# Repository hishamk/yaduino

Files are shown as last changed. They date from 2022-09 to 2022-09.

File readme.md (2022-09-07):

## The Yaduino - An ATmega328P playground
So this is my first stab at designing a microcontroller board. I call it Yaduino - Yet Another Arduino (the missing r is deliberate!) :)

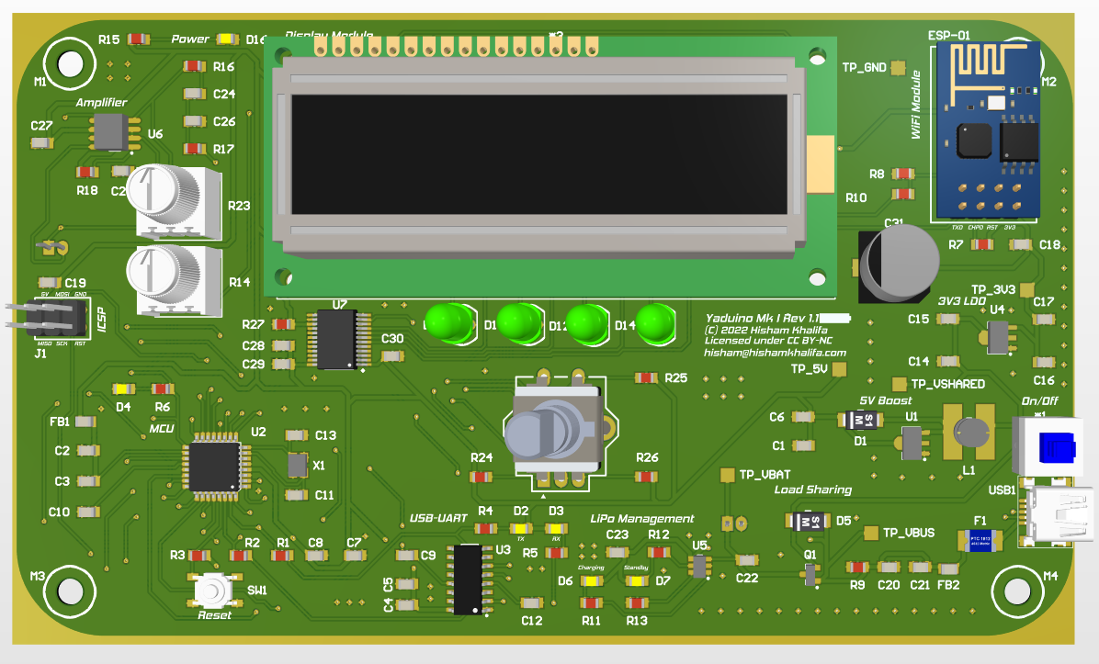
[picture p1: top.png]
Top PCB image


Since I used CircuitMaker for schematic and PCB design, this project is also hosted on [CircuitMaker's project hub](https://circuitmaker.com/Projects/Details/HishamKhalifa-2/ATmega328-Playground).

A [YouTube video](https://youtu.be/OaU7GNxLcCE) of the Yaduino.

### Design Goals
This project does not necessarily "make sense" since a million other boards could do more, with less components and a smaller footprint. My aim with this project was to learn microcontroller board design and to figure out how to implement my (somewhat arbitrary) design goals for the 8-bit ATmega328 microcontroller.

The choice of MCU and components was mainly driven by the fact that I also had most materials (or closely related counterparts) to breadboard most of the design before committing it to PCB manufacture. Besides, what's the fun in using other boards when you can learn to make your own and have fun while at it?

 1. Should function as a regular Arduino (complete with ICSP for burning
    the bootloader).

 2. Should use as many SMD parts as possible from JLC's parts library so
    that I can utilize their assembly service to some extent.
    
 3.  Should include easily accessible headers for plugging in either an
    I2C VFD/OLED display or a serial 1602A display.
    
 4. Should work with a LiPo as well as USB power and have a proper
    battery management circuit, boost circuit and load sharing circuit.
    
 5. Should have a provision for plugging in an ESP-8266 ESP-01 module to add WiFi
    access (a little bit of 32-bit goodness at play here).
    
 6. Should have at least one optional IC, such as a demux, with some
    blinkenlights for good measure. This may be disabled using a solder
    jumper.
    
 7.  Should have some input facility, such as a rotary encoder/button.
    
 8.  Should look good without a case as well as with a case.
    
 9. Silkscreen should be informative and cool, because why not.

### Fixed Issues 

This board has been fully built, tested and debugged. All mistakes listed below have been fixed as of this version (but not built, as the bodge wire version with the fixes works fine).

The issues were:

 1. ESP stability. ESP-8266 ESP-01 requires more than 200mA at startup. This needs clean power. Fixed with 100uF bypass.

 2. Board was receiving serial data (RX) but was unable to transmit (TX). Culprit was too small resistor value on TX LED. It was 1K. Changed to 3K3 and that fixed it. It seems the LED was drawing too much current away from the actual 
TX signal destined to the CH340C USB-UART IC.

3. Forgot to connect supply on the charge management IC! Bodge wire to the rescue!

4. Messed up volume POT connections. Had full resistance of POT (10K or 20K depending on POT used), instead of actual setting. Fixed with bodge wire and POT pin gymnastics and PCB trace cut.

 5. 1602A lines-to-pins silkscreen on bottom side was incorrect in a couple of places.
 
### Assembly

I ordered the PCBs from JLC and utilized their assembly service. The main components that I had to solder myself where: the ATmega328P-AU (drag solder and some solder wick does the trick), headers, POTS and the various bodge/fixes.

### Programming
  
So once the board is full assembled, you'll want to burn the Arduino bootloader onto it. Assuming you have a factory-fresh ATmega 328 with no set fuses, this process should not pose any issues.

*Tip*
You can use [AVRFuses](https://vonnieda.org/software/avrfuses) to check the fuse settings on the ATmega328 using a USBasp connected to the ICSP header.

To burn the bootloader and start uploading Arduino sketches:

1. Connect a USBasp to the ICSP header on the Yaduino and the other end of the cable to your computer.

2. Install the [MiniCore](https://github.com/MCUdude/MiniCore) package on your computer (and before that, the Arduino IDE if not already installed).

3. In the Arduino IDE, select MiniCore | Atmega328 for the Board, then select External 16MHz for clock, 2.7v for BOD, EEPROM retained for EEPROM, LTO Disabed for LTO Compiler, 328P/328PA for the Variant, YES (UART10) for the Bootloader.

4. Set the programmer to "USBasp (MiniCore)".

5. Select Burn Bootloader.

6. Once the bootloader is burned successfully, select AVRISP mkII (MiniCore) for the programmer.

7. You may disconnect the USBasp at this point and connect via the micro USB connection. Your board is now ready to receive and run Arduino code.

### ESP-8266 / WiFi

 To use an ESP-8266 ESP-01 with the Yaduino, you'll need to use the [WiFIESPAT](https://github.com/jandrassy/WiFiEspAT) library.

I opted to use [v2.2.0.0](https://github.com/jandrassy/UnoWiFiDevEdSerial1/wiki/files/ESP8266-1MB-tx1rx3-AT_V2.2.zip) of the firmware. You may need to update the firmware using a basic circuit and a USB-UART board (Google it, it's out there). Make sure you have a 100uF bypass cap if you're facing temperamental issues with either 
updating the firmware or testing it. A lot of these schematics on the net do not have this cap specified.

Once your firmware is updated, you'll have to change the baud rate to 9600. You may do this manually using AT commands after updating the fimrware, or you could:

1. Plug the ESP-8266 into the Yaduino.

2. Load the ChangeATBaudRate sketch in the WiFiESPAT library's examples folder.

3. Change the Software Serial ports to 11 and 10 instead of 6 and 7.

4. Upload sketch.

5. Your ESP-8266 should now work at 9600.

The reason Software Serial is used for the ESP-8266 connection is due to the fact that the hardware serial pins are also used for the 1602A display. Yes, I know, if you use an I2C display this wouldn't be an issue - but I wanted to 
design it with this constraint to see if I can get everything working fine.

### Example Code

 The example code does a few things:

1. Displays text on 1602A.

2. Connects to WiFi (make sure you run the WiFiESPAT examples folder sketch "SetUp PersistentWiFiConnection" to set your WiFi details first.)

3. Displays IP address and some other fidgety things on clicking/rotating.

4. Runs a telnet server. Connect to port 2323 from another machine and type in a message. It'll get displayed on the Yaduino!

### Enclosures

I've designed and printed a few [enclosures](https://a360.co/3RtZ853) using Fusion 360 and printed them on a Prusa Mini+ using PLA filaments.

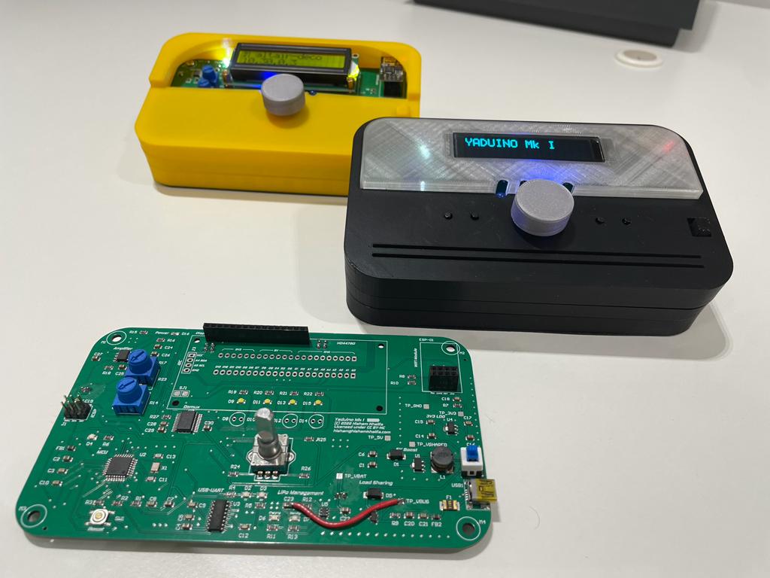
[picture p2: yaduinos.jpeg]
Yaduinos image


## Inspiration

This project is partially inspired by the [Simonduino](https://circuitmaker.com/Projects/Details/Andre-LaMothe/Simonduino-Color-Match-Game) project which in turn is based off the Arduino Nano. The Simonduino is used in Andre LaMothe's course on [Udemy](https://www.udemy.com/course/crash-course-electronics-and-pcb-design/).

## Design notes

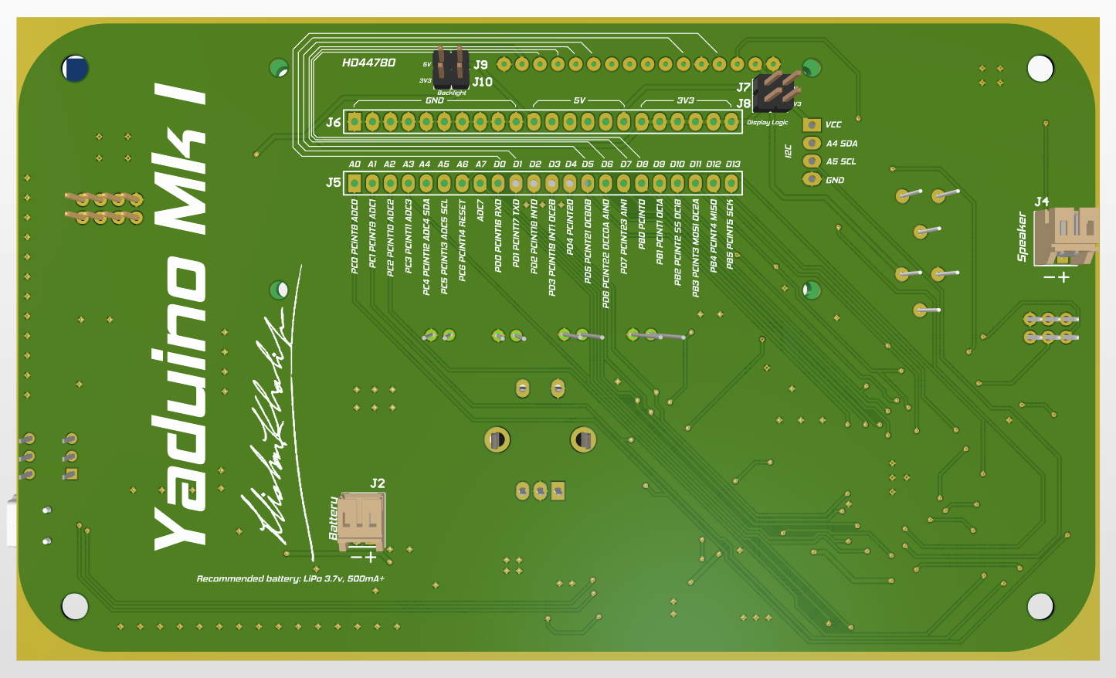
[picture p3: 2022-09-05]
bottom.png

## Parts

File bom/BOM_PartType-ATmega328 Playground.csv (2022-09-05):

Comment | Designator | Footprint | Description | LibRef | Quantity
E-Switch TL2285EE | *1 | E-Switch TL2285EE-Footprint-1 | Switch Push Button ON ON DPDT Plunger 0.1A 30VDC Latching PC Pins Thru-Hole | CMP-c0ee09f4e8cc1f29-8 | 1
Generic rotary encoder | *2 | PCB-o3j4y8d2fld7qcbr9m3z-1 | Generic rotary encoder | CMP-xheecen9eoauhc53c92k-2 | 1
LCD 1602A | *3 | PCB-ex3up7xxohmyvq6bxg3y-1 | LCD Display | CMP-27dcefe9db18f81b-4 | 1
22uF | C1, C6, C7 | PCB-6lexfyg45u8dooebomjp-1 | Generic 805 ceramic cap | CMP-2j4q9hwmgv2koyvfzfsm-2 | 3
10uF | C2, C4, C14, C16, C20, C22, C23, C27, C29, C30 | PCB-6lexfyg45u8dooebomjp-1 | Generic 805 ceramic cap | CMP-2j4q9hwmgv2koyvfzfsm-2 | 10
0.1uF (100nF) | C3, C5, C8, C9, C10, C12, C15, C17, C18, C19, C21, C28 | PCB-6lexfyg45u8dooebomjp-1 | Generic 805 ceramic cap | CMP-2j4q9hwmgv2koyvfzfsm-2 | 12
15pF | C11, C13 | PCB-6lexfyg45u8dooebomjp-1 | Generic 805 ceramic cap | CMP-2j4q9hwmgv2koyvfzfsm-2 | 2
0.39uF (390nF) | C24 | PCB-6lexfyg45u8dooebomjp-1 | Generic 805 ceramic cap | CMP-2j4q9hwmgv2koyvfzfsm-2 | 1
1uF | C25, C26 | PCB-6lexfyg45u8dooebomjp-1 | Generic 805 ceramic cap | CMP-2j4q9hwmgv2koyvfzfsm-2 | 2
100uF | C31 | EEHZC1H101P | Generic 805 electrolytic capacitor | CMP-vk94xb3d6va75m91xos3-1 | 1
SS14 DO214 | D1, D5 | DO-214 | SS14 DO214 | CMP-1ixnt5ul191www8k67rw-2 | 2
Generic 805 LED | D2, D3, D4 | PCB-6lexfyg45u8dooebomjp-1 | Generic 805 LED | CMP-3miidwgmeqlikwr8bjjy-1 | 3
Charge Status LED | D6 | PCB-6lexfyg45u8dooebomjp-1 | Generic 805 LED | CMP-3miidwgmeqlikwr8bjjy-1 | 1
Standby Status LED | D7 | PCB-6lexfyg45u8dooebomjp-1 | Generic 805 LED | CMP-3miidwgmeqlikwr8bjjy-1 | 1
Output LED | D8, D10, D12, D14 | PCB-b5vk7vz0xhkw7l0fnova-1 | LED Uni-Color Green 2-Pin T-1 3/4 Bulk | CMP-92bb5b2eff764d7c-3 | 4
2 | D9 | PCB-6lexfyg45u8dooebomjp-1 | Generic 805 LED | CMP-3miidwgmeqlikwr8bjjy-1 | 1
 | D11, D13, D15 | PCB-6lexfyg45u8dooebomjp-1 | Generic 805 LED | CMP-3miidwgmeqlikwr8bjjy-1 | 3
Status LED 2 | D16 | PCB-6lexfyg45u8dooebomjp-1 | Generic 805 LED | CMP-3miidwgmeqlikwr8bjjy-1 | 1
Jameco Valuepro ESP8266 ESP-01S | ESP-01 | Jameco Valuepro ESP8266 ESP-01S-Footprint-1 | ESP-01S ESP8266 WiFi Module | CMP-8c81432480f65346-5 | 1
Resettable protection fuse | F1 | PCB-jtgmhik4xw0hzz22xc7c-1 | PTC Resettable Fuse 0.5A(hold) 1A(trip) 15V 100A 0.8W 0.15s 0.15Ohm SMD Solder Pad 1812 T/R | CMP-277735-10 | 1
1.5K@100MHz | FB1, FB2 | PCB-d2agyush773fxqrs9gs3-1 | PBY201209T 1500R 1000mA 0, 30R RoHSconf | CMP-31b8f9c7a15aee7f-1 | 2
 | J1 | PCB-2h1t0rpz2tx2wsc79kkt-1 | 2.54mm (0.1") Pitch DIL Vertical PC Tail Pin Header, 6.1mm mating pin height, tin, 3+3 contacts | M20-9980346 | 1
JST S2B-PH-K-S (LF)(SN) | J2 | PCB-bjczsn0p3ptzfqad6r12-1 | Conn Shrouded Header (4 Sides) HDR 2 POS 2mm Solder RA Thru-Hole Box | CMP-ffbd36e62648207a-2 | 1
Generic 1.25mm 4 pin female header | J3 | PCB-aav6o8fn6okscn0g86ph-1 | Generic 1.25mm 4 pin female header | CMP-0es61uybg75kwez52rvg-1 | 1
Speaker | J4 | PCB-bjczsn0p3ptzfqad6r12-1 | Conn Shrouded Header (4 Sides) HDR 2 POS 2mm Solder RA Thru-Hole Box | CMP-ffbd36e62648207a-2 | 1
Generic 2.54mm 22 pin female header | J5, J6 | PCB-aav6o8fn6okscn0g86ph-1 | Generic 2.54mm 22 pin female header | CMP-b4ui2xh0qsgjy2za9ieg-1 | 2
 | J7, J8, J9, J10 | PCB-header | Connector, Through Hole, Header, 2, 2.54 mm 2pin | CMP-74e0bf2ff245ab27-13 | 4
HRO U-F-M5SS-W-2 | J11 | PCB-udy8oed33uo11narwln1-1 | Conn; Data; USB; Mini-B; SMT; Rt Angle; Solder Tabs; On-The-Go; PCB Pegs; LF | CMP-d87211734df407b5-14 | 1
22uH | L1 | PCB-jclg0i9eyiwxcv2vi73d-1 | Inductor Power Wirewound 22uH 20% 1KHz 20Q-Factor Ferrite 1.5A 110mOhm DCR T/R | CMP-a103680bca1b7ec4-1 | 1
Keystone 4816 | M1, M2, M3, M4 | PCB-mb8dqtsky67usueely79-1 | TEKTON 4816 1/2-Inch Drive Shallow Impact Socket Set, SAE, 15-Piece | CMP-d4321d38e40b0bf5-1 | 4
Alpha & Omega Semiconductor AO3401A | Q1 | PCB-kx100zt0qwbp6gbfpfbn-1 | MOSFET P-CH 30V 4A SOT23 | CMP-832298-9 | 1
1K | R1, R2, R5, R6, R10, R11, R12, R17 | PCB-6lexfyg45u8dooebomjp-1 | Generic 805 resistor | CMP-5huzuqma9w3n6iha3gac-1 | 8
10K | R3, R7, R9, R18, R24, R25, R26, R27 | PCB-6lexfyg45u8dooebomjp-1 | Generic 805 resistor | CMP-5huzuqma9w3n6iha3gac-1 | 8
3K3 | R4 | PCB-6lexfyg45u8dooebomjp-1 | Generic 805 resistor | CMP-5huzuqma9w3n6iha3gac-1 | 1
2K2 | R8 | PCB-6lexfyg45u8dooebomjp-1 | Generic 805 resistor | CMP-5huzuqma9w3n6iha3gac-1 | 1
2K | R13 | PCB-6lexfyg45u8dooebomjp-1 | Generic 805 resistor | CMP-5huzuqma9w3n6iha3gac-1 | 1
0-10K | R14 | RES-Bourns-3386 | Res Cermet Trimmer 5K Ohm 10% 1/2W 1(Elec)/1(Mech)Turn 8.38mm (9.53 X 9.53 X 10.41mm) Pin Thru-Hole Tube | CMP-57749e7438e988b3-1 | 1
470R | R15, R19, R20, R21, R22 | PCB-6lexfyg45u8dooebomjp-1 | Generic 805 resistor | CMP-5huzuqma9w3n6iha3gac-1 | 5
20K | R16 | PCB-6lexfyg45u8dooebomjp-1 | Generic 805 resistor | CMP-5huzuqma9w3n6iha3gac-1 | 1
0-100K | R23 | RES-Bourns-3386 | Res Cermet Trimmer 5K Ohm 10% 1/2W 1(Elec)/1(Mech)Turn 8.38mm (9.53 X 9.53 X 10.41mm) Pin Thru-Hole Tube | CMP-57749e7438e988b3-1 | 1
Jumper pads | SJ1 | New footprint 1 | Jumper pads | CMP-4ca9tqewk6jxev977wve-7 | 1
 | SW1 | PCB-3slrmfp54cqpjmkc7eq7-1 | Switch Tactile N.O. SPST Round Button Gull Wing 0.02A 15VDC 1000000Cycles 1.569N SMD T/R | CMP-f30a391dc9bb2ccd-2 | 1
2x2mm-pad | TP_3V3, TP_5V, TP_GND, TP_VBAT, TP_VBUS, TP_VSHARED | PCB-iek5qk9ganu4yn12lo6h-1 | Raychem; SMT Circuit probe pad, 0805, 0R0 RCT | RCT-0C | 6
ME2108A/50 | U1 | SOT-89-MB3_N | DC/DC Step Up Converter | CMP-w3jwqw8rtfk6e8mw7z1w-1 | 1
ATMEGA328P-AU | U2 | TQFP32-08 | Embedded microcontroller ATMEGA328P-AU TQFP 32 (7x7) Microchip Technology 8-Bit 20 MHz I/O number 23 | ATMEGA328P-AU | 1
CH340C UART | U3 | CYP-SX16_L | CH340C UART | CMP-cjy4raao81rihiu0fmjx-3 | 1
Holtek HT7333A | U4 | SOT-89_M | Fixed Low Drop Positive Voltage Regulator, 3.3V, 4-Pin SOT-89, 3-Pin TO-02, Tape and Reel | CMP-f9d135d015f72616-1 | 1
TP4057 Linear Li-Ion Battery Charger 500mA | U5 | DBV6_L | TP4057 Linear Li-Ion Battery Charger 500mA | CMP-pmi864c5akpbqamag5jn-2 | 1
BL62810SO-R | U6 | SOIC-SN8_M | 1.1W x 1 @ 8O 2.2V ~ 5.5V Class AB SOIC-8_150mil Audio Power OpAmps ROHS | CMP-pd4wvmbbrd8m1k4bw0eq-2 | 1
TI CD74HC4067 (SSOP) | U7 | PCB-9xotwbubxedzd6tjqrkr-1 | High Speed CMOS 16-Channel Analog Multiplexer/Demultiplexer 24-SSOP -55 to 125 | CMP-106ed96303d9cfa9-15 | 1
16MHz CL 9pF | X1 | PCB-73bh49k2ct94buydgloj-1 | Crystal 16Mhz 3225 SMD | CMP-c6a10a47defa1966-1 | 1

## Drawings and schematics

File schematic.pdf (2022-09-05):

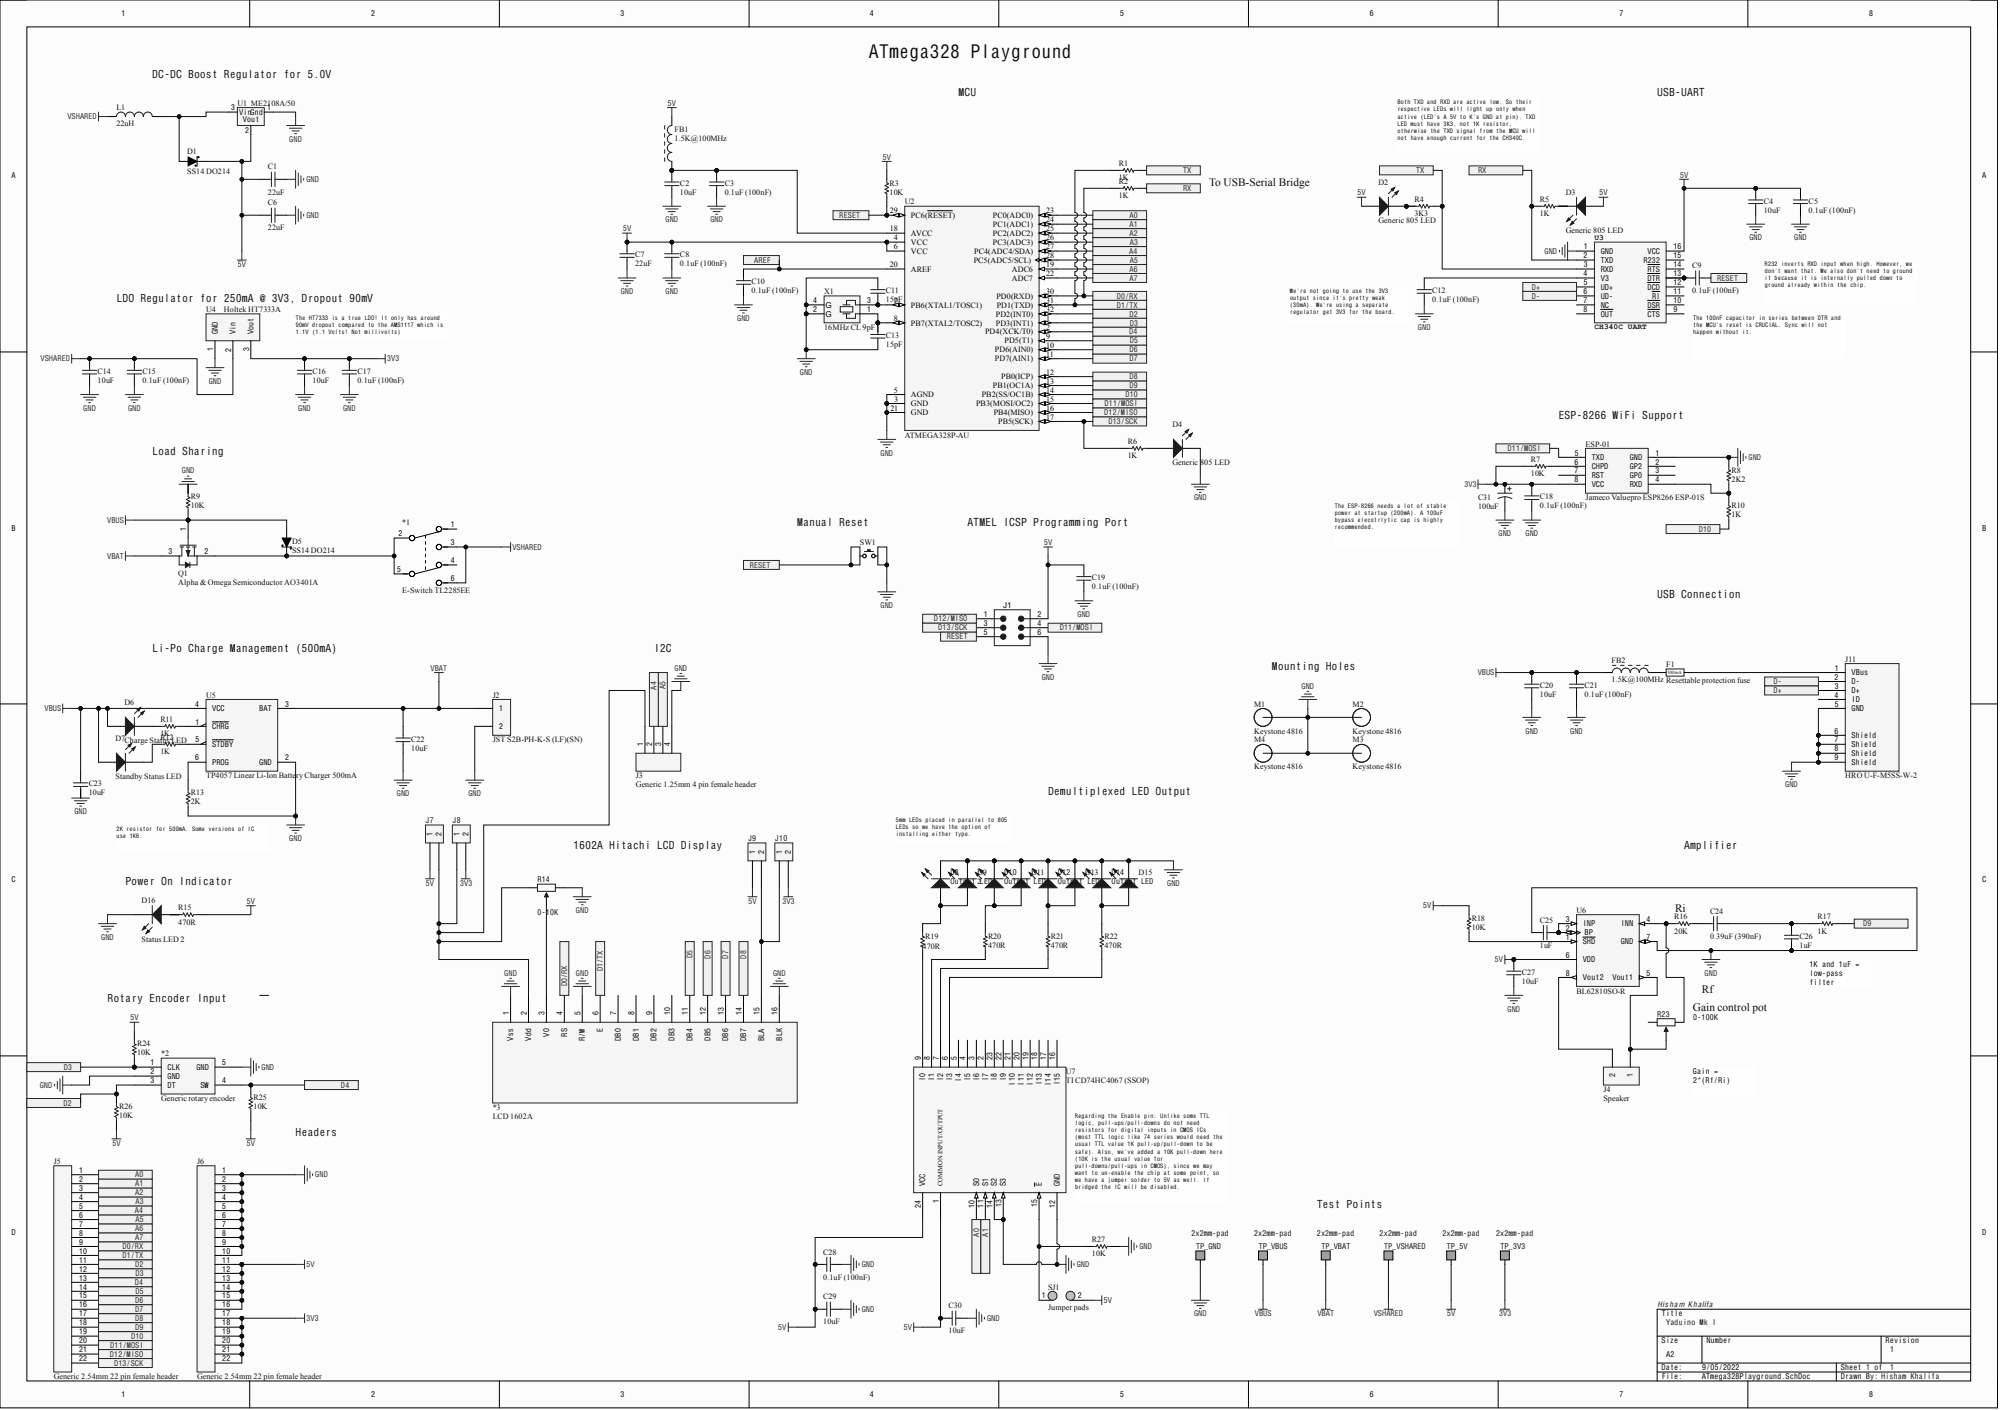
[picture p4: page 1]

DC-DC Boos t Regu l a t o r f o r 5 . 0V

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

LDO Regu l a t o r f o r 250mA @ 3V3 , Dr opou t 90mV

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

GND 1 U4 Holtek HT7333A The HT7333 i s a t r ue LDO! I t on l y has a r ound

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

90mV d r opou t compa r ed t o t he AMS1117 wh i ch i s

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

L i -Po Cha r ge Managemen t ( 500mA)

JST S2B-PH-K-S (LF)(SN)

TP4057 Linear Li-Ion Battery Charger 500mA

Generic 1.25mm 4 pin female header

Demu l t i p l e x ed LED Ou t pu t

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

2K r es i s t o r f o r 500mA . Some ve r s i ons o f I C
use 1K6 .

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

Generic 2.54mm 22 pin female header

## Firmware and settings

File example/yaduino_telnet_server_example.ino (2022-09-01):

#include <SoftwareSerial.h>

#include <LiquidCrystal.h>

#include <EncoderButton.h>

#include <WiFiEspAT.h>

#define BIT(n, i)(n >> i & 1)
#define esp8266Speed 9600

SoftwareSerial esp8266(11, 10); // rx, tx

int lastPosition;

WiFiClient client;

const int MAX_CLIENTS = 3;
const int CLIENT_CONN_TIMEOUT = 3600; // seconds. 1 hour
WiFiServerPrint server(2323);

LiquidCrystal lcd(0, 1, 5, 6, 7, 8); // 0 = rxPin, 1 = txPin Parameters: (rs, enable, d4, d5, d6, d7)
EncoderButton eb1(2, 3, 4); // INT0 and INT1 hardware interrupt pins are 2 and 3. We use them so that we can read the encoder using interrupts rather than polling on every cycle which would be laggy/unreliable!

String s;

byte yaduinoLogo[] = {
  B10100,
  B10100,
  B11100,
  B00110,
  B11101,
  B00101,
  B00101,
  B00110
};

byte wifiLogo[] = {
  B10101,
  B10101,
  B11101,
  B11101,
  B00000,
  B11101,
  B11001,
  B10001
};

byte ok[] = {
  B11110,
  B10010,
  B10010,
  B11110,
  B00101,
  B00110,
  B00110,
  B00101
};

byte no[] = {
  B10010,
  B11010,
  B10110,
  B10010,
  B01111,
  B01001,
  B01001,
  B01111
};

byte smiley[] = {
  B11011,
  B11011,
  B00100,
  B00100,
  B10001,
  B10001,
  B01110,
  B00000
};

void setup() {
  // set up the LCD's number of columns and rows:
 
  lcd.begin(16, 2);
  lcd.createChar(0,yaduinoLogo);
  lcd.createChar(1,wifiLogo);

  //Link the event(s) to your function
  eb1.setClickHandler(onEb1Clicked);
  eb1.setEncoderHandler(onEb1Encoder);

  pinMode(14, OUTPUT);
  pinMode(15, OUTPUT);
  pinMode(16, OUTPUT);

  digitalWrite(14, LOW);
  digitalWrite(15, LOW);
  digitalWrite(16, LOW);

  for (int source = 0; source < 4; source++) {
    delay(300);
    selectSource(source);
  }

  delay(300);
  selectSource(0);

  esp8266.begin(esp8266Speed);
  WiFi.init(esp8266);
  WiFi.hostname("yaduino-yellow");

  printWelcome();
  delay(2000);
  lcdReset();

  if (WiFi.status() == WL_NO_MODULE) {
    lcd.print("WiFi error!");
    // don't continue
    while (true);
  }

  // waiting for connection to Wifi network set with the SetupWiFiConnection sketch
  lcd.write(byte(1));
  lcd.print(" Connecting");
  while (WiFi.status() != WL_CONNECTED) {
    delay(1000);
    lcd.print('.');
  }

  server.begin(MAX_CLIENTS, CLIENT_CONN_TIMEOUT);
  printNetInfo();
}

void lcdReset() {
  lcd.clear();
//  lcd.blink();
  lcd.setCursor(0, 0);
}

void printNetInfo() {
  lcdReset();
  IPAddress ip = WiFi.localIP();
  lcd.write(byte(1));
  lcd.print(" ");
  lcd.print(WiFi.SSID());
  lcd.setCursor(0, 1);
  lcd.print(ip);
}

void printLove() {
  lcdReset();
  lcd.print("I love you.");
  lcd.setCursor(0, 1);
  lcd.print(":)");
}

void printWelcome() {
  lcdReset();
  lcd.print("   Welcome to");
  lcd.setCursor(0, 1);
  lcd.print(" ");
  lcd.write(byte(0));
  lcd.print(" Yaduino Mk I");
}

void loop() {
  eb1.update();

  WiFiClient client = server.available(); // returns first client which has data to read or a 'false' client
  if (client) { // client is true only if it is connected and has data to read
    s = client.readStringUntil('\n'); // read the message incoming from one of the clients
    s.trim(); // trim eventual \r
    updateMessage(s);
    client.print("echo: "); // this is only for the sending client
    server.println(s); // send the message to all connected clients
    server.flush(); // flush the buffers
  }
}

void updateMessage(String msg) {
  lcdReset();
  lcd.print(msg);
  if (s.length() > 16) {
    delay(1000);
  }
}

void onEb1Clicked(EncoderButton & eb) {
  tone(9, 100, 10);
  //  lcd.clear();
  lcd.setCursor(0, 0);
  // Print a message to the LCD.
  lcd.print("Button click   ");
  lcd.setCursor(13, 0);
  lcd.print(eb.clickCount());
  lcd.setCursor(0, 1);
  lcd.print("                ");

  if (eb.clickCount() == 2) {
    printNetInfo();
  } else if (eb.clickCount() == 3) {
    printLove();
  }
}


void levelSet(int d) {
  static int level=-1;
  lcd.setCursor(0,0);
  lcd.print("VOLUME          ");
  level += d;

  lcd.setCursor(0,1);
  for (int x = 0; x<= level; x++) {
    lcd.print((char)0xFF);
  }
  int blank = 16 - level;
  if (blank>0) {
    lcd.print(" ");
  }
}

void onEb1Encoder(EncoderButton & eb) {
  if (eb.position() >= 0 && eb.position() <= 16) {
    if (eb.position() >= 0 && eb.position() <= 3) {
      selectSource(eb.position());
    }
    tone(9, 1000, 25);
  if (eb.increment()==1) {
    levelSet(1);
  } else if (eb.increment()==-1) {
    levelSet(-1);
   } 
  
  } else {
  eb.resetPosition(lastPosition);
    tone(9, 20, 150);
  }

  lastPosition = eb.position();
}

void selectSource(int x) {
  int p14 = BIT(x, 0);
  int p15 = BIT(x, 1);
  int p16 = BIT(x, 2);

  digitalWrite(14, p14);
  digitalWrite(15, p15);
  digitalWrite(16, p16);
}

void loadSymbols() {
  lcd.createChar(0, yaduinoLogo);
  lcd.createChar(1, wifiLogo);
  lcd.createChar(2, ok);
  lcd.createChar(3, no);
  lcd.createChar(4, smiley);
}
